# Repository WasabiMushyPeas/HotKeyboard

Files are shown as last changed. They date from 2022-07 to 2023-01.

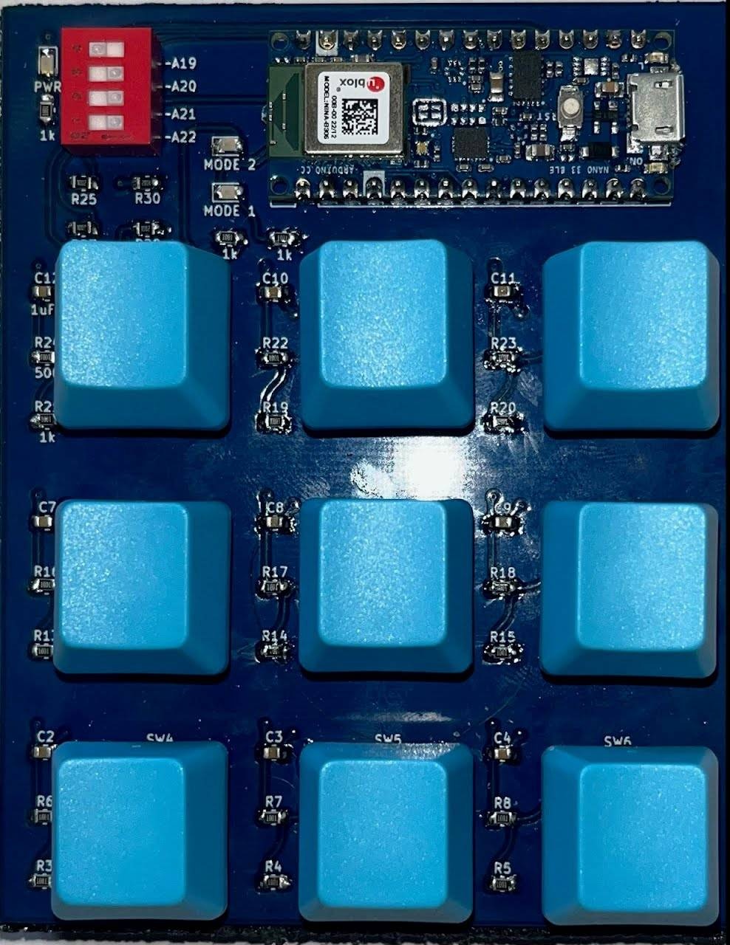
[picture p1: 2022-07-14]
pcbAndMaterials/signal-2022-07-12-220346.jpeg

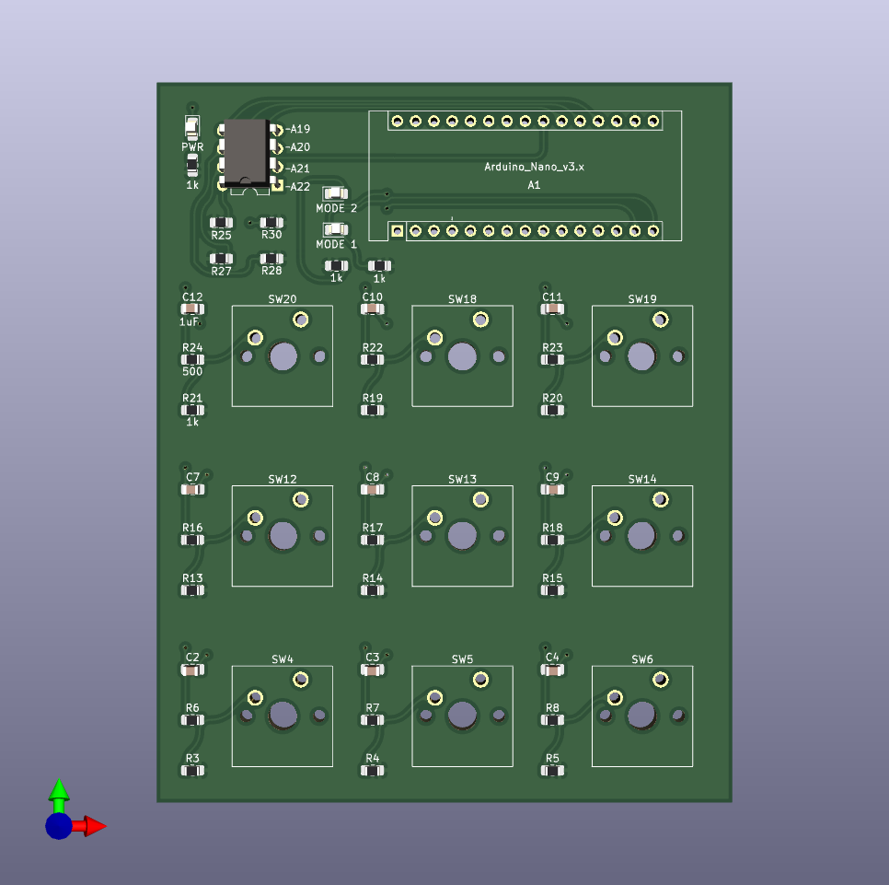
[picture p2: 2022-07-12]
pcbAndMaterials/PCB_Picture_Front.png

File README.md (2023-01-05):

# HotKey board
This is a simple Arduino project that allows Arduino boards that don't support Arduino's HID library to simulate key presses through a serial monitor accessed by python which than simulates the key presses. This repo also includes a PCB that connects 9 keyboard switches status LEDs and a DIP switch.
# Installation
- Download this git repo
- upload the [hotKeyBoard.ino](https://github.com/WasabiMushyPeas/HotKeyboard/blob/main/hotKeyBoard.ino) to your Arduino through the [Arduino IDE](https://www.arduino.cc/en/software)
- Pip install these Python libraries
`
pip install input
`
`
pip install serial
`
- make sure ser = serial. Serial('/dev/ttyACM0') in [keyBoardInterpriter.py](https://github.com/WasabiMushyPeas/HotKeyboard/blob/main/keyBoardInterpriter.py) on line 12 you replace '/dev/ttyACM0' with the port that your Arduino is connected to
- then run the python program
# Customization
if you want to customize your keyboard shortcuts edit the [keyBoardShortcuts.txt](https://github.com/WasabiMushyPeas/HotKeyboard/blob/main/keyBoardShortcuts.txt) and put your keyboard shortcuts in the text file like so:
```
cmd|g #cmd is short for the windows key or the command key on mac
Ctrl|h #this the command Ctrl+h | separates the key presses
Ctrl|Alt|Delete #This will be bound to the 3rd key and Ctrl|h the 2nd key and cmd|g the 1st key you can put up to 27. 
#The first key is the top left going from left to right then up to down.
```
> :warning: **Make sure you delete all the comments in [keyBoardShortcuts.txt](https://github.com/WasabiMushyPeas/HotKeyboard/blob/main/keyBoardShortcuts.txt) can not have comments**
# Other
if you need to excute commands on linux check out [the awesomewm branch](https://github.com/WasabiMushyPeas/HotKeyboard/tree/awesomewm)

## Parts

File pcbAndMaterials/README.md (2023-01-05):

# Custom PCB
if you would like to use my PCB design you need:
  - 0805 1k and 500ohm resistors and LEDs and 1uf capacitors
  - Arduino nano BLE
  - DIP switch with four switches
  - Cherry MX switches

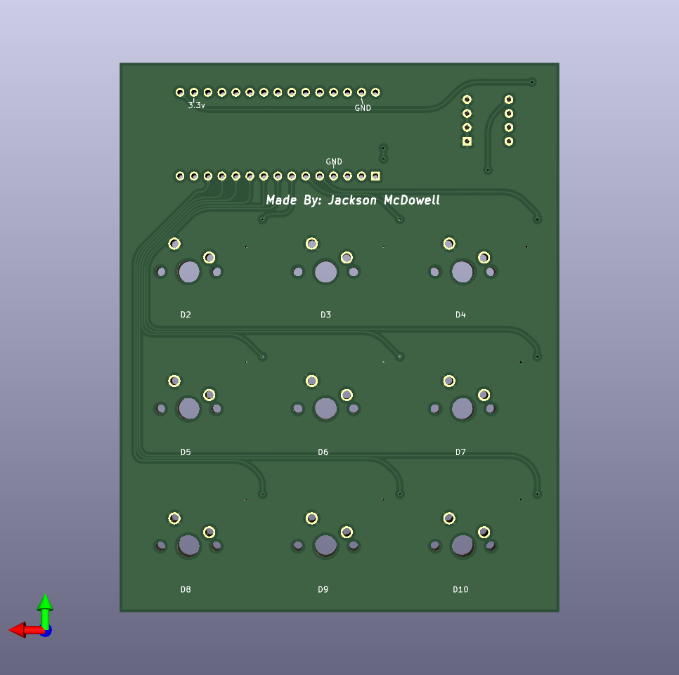
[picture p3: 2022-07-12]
pcbAndMaterials/PCB_Picture_Back.png

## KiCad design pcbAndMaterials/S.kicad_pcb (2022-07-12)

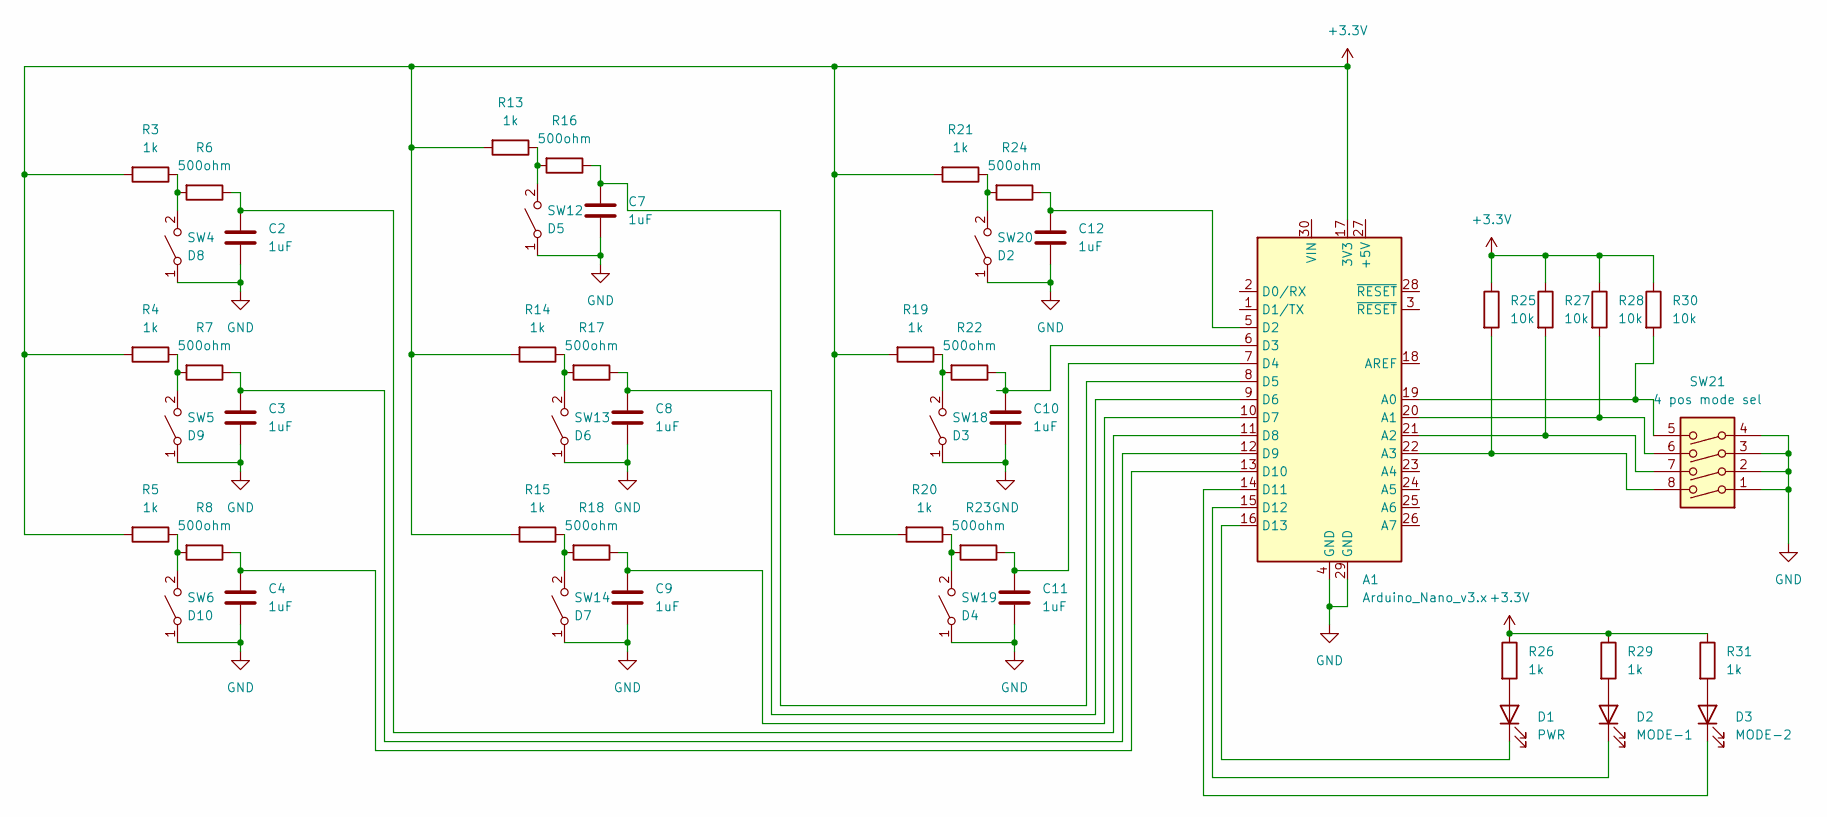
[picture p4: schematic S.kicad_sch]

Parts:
A1: Arduino_Nano_v3.x; Arduino_Nano
C2, C3, C4, C7, C8, C9, C10, C11, C12: 1uF; C_0805_2012Metric_Pad1.18x1.45mm_HandSolder
D1: PWR; LED_0805_2012Metric_Pad1.15x1.40mm_HandSolder
D2: MODE-1; LED_0805_2012Metric_Pad1.15x1.40mm_HandSolder
D3: MODE-2; LED_0805_2012Metric_Pad1.15x1.40mm_HandSolder
R3, R4, R5, R13, R14, R15, R19, R20, R21, R26, R29, R31: 1k; R_0805_2012Metric_Pad1.20x1.40mm_HandSolder
R6, R7, R8, R16, R17, R18, R22, R23, R24: 500ohm; R_0805_2012Metric_Pad1.20x1.40mm_HandSolder
R25, R27, R28, R30: 10k; R_0805_2012Metric_Pad1.20x1.40mm_HandSolder
SW4: D8; SW_Cherry_MX_1.00u_PCB
SW5: D9; SW_Cherry_MX_1.00u_PCB
SW6: D10; SW_Cherry_MX_1.00u_PCB
SW12: D5; SW_Cherry_MX_1.00u_PCB
SW13: D6; SW_Cherry_MX_1.00u_PCB
SW14: D7; SW_Cherry_MX_1.00u_PCB
SW18: D3; SW_Cherry_MX_1.00u_PCB
SW19: D4; SW_Cherry_MX_1.00u_PCB
SW20: D2; SW_Cherry_MX_1.00u_PCB
SW21: 4 pos mode sel; DIP-8_W7.62mm

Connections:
+3V3: A1.17 (3V3), R3.2, R4.2, R5.2, R13.2, R14.2, R15.2, R19.2, R20.2, R21.2, R25.1, R26.1, R27.1, R28.1, R29.1, R30.1, R31.1
GND: A1.4 (GND), A1.29 (GND), C2.2, C3.2, C4.2, C7.2, C8.2, C9.2, C10.2, C11.2, C12.2, SW4.1 (A), SW5.1 (A), SW6.1 (A), SW12.1 (A), SW13.1 (A), SW14.1 (A), SW18.1 (A), SW19.1 (A), SW20.1 (A), SW21.1, SW21.2, SW21.3, SW21.4
unnamed: A1.5 (D2), C12.1, R24.1
unnamed: A1.6 (D3), C10.1, R22.1
unnamed: A1.7 (D4), C11.1, R23.1
unnamed: A1.8 (D5), C7.1, R16.1
unnamed: A1.9 (D6), C8.1, R17.1
unnamed: A1.10 (D7), C9.1, R18.1
unnamed: A1.11 (D8), C2.1, R6.1
unnamed: A1.12 (D9), C3.1, R7.1
unnamed: A1.13 (D10), C4.1, R8.1
unnamed: A1.14 (D11), D3.1 (K)
unnamed: A1.15 (D12), D2.1 (K)
unnamed: A1.16 (D13), D1.1 (K)
unnamed: A1.19 (A0), R30.2, SW21.5
unnamed: A1.20 (A1), R28.2, SW21.6
unnamed: A1.21 (A2), R27.2, SW21.7
unnamed: A1.22 (A3), R25.2, SW21.8
unnamed: D1.2 (A), R26.2
unnamed: D2.2 (A), R29.2
unnamed: D3.2 (A), R31.2
unnamed: R3.1, R6.2, SW4.2 (B)
unnamed: R4.1, R7.2, SW5.2 (B)
unnamed: R5.1, R8.2, SW6.2 (B)
unnamed: R13.1, R16.2, SW12.2 (B)
unnamed: R14.1, R17.2, SW13.2 (B)
unnamed: R15.1, R18.2, SW14.2 (B)
unnamed: R19.1, R22.2, SW18.2 (B)
unnamed: R20.1, R23.2, SW19.2 (B)
unnamed: R21.1, R24.2, SW20.2 (B)

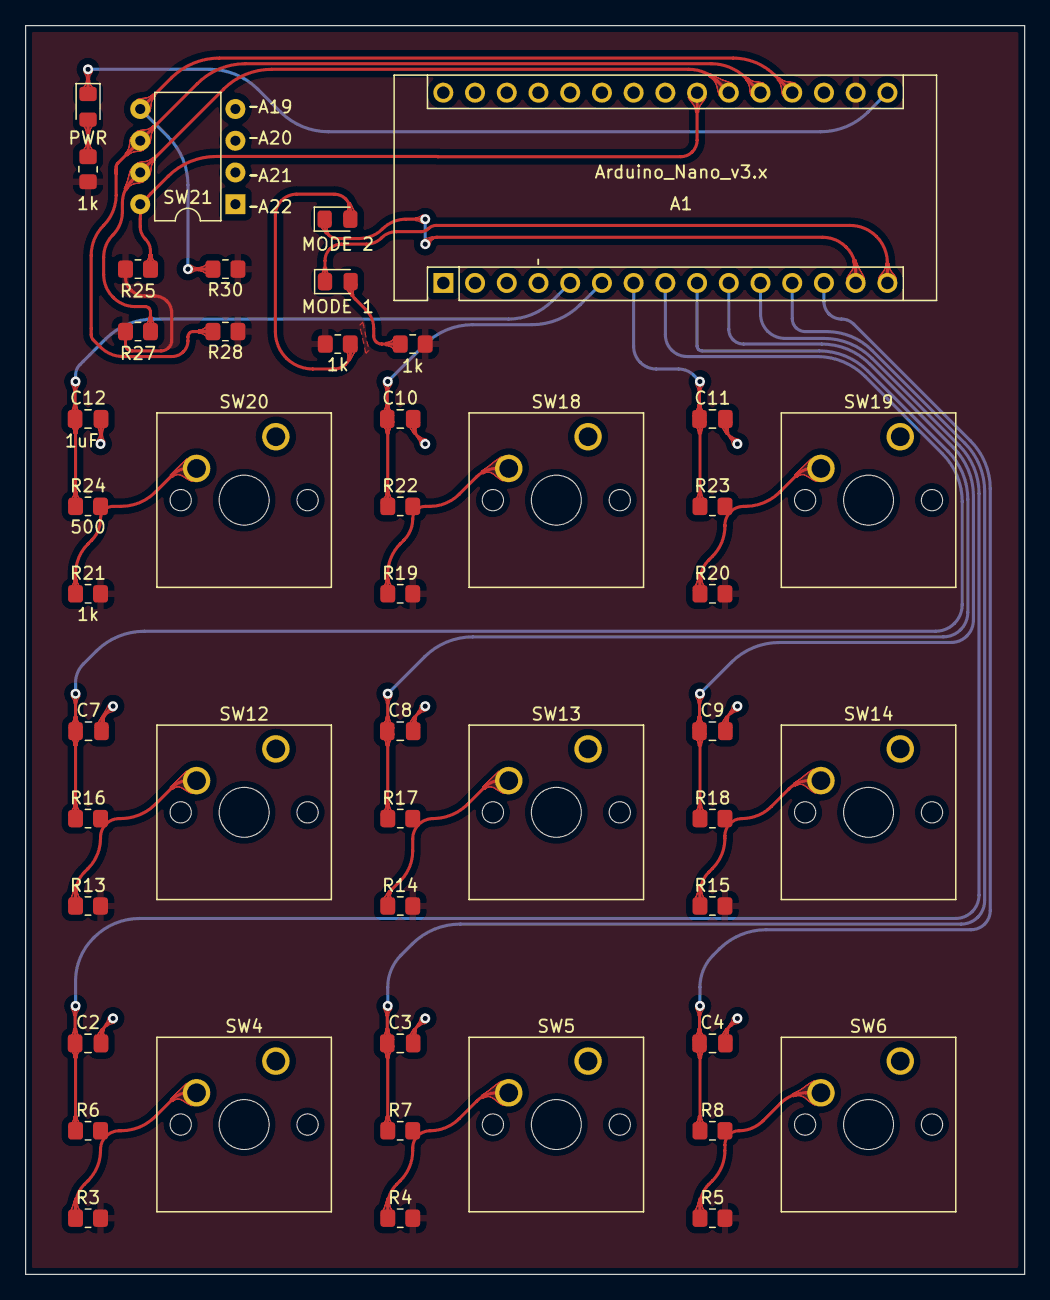
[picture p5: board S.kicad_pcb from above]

Board: 2 copper layers, 80.0 x 100.0 mm, 48 parts (0 on the bottom side), 30 nets.

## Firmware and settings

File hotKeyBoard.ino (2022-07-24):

const int BlueLEDbulitIn = 24;
const int RedLEDbulitIn = 22;
const int dipSwitch4 = A0;
const int dipSwitch3 = A1; 
const int dipSwitch2 = A2; 
const int dipSwitch1 = A3; 
const int mode2 = 11; 
const int mode1 = 12; 
const int sw20 = D2;
const int sw18 = D3;
const int sw19 = D4;
const int sw12 = D5;
const int sw13 = D6;
const int sw14 = D7;
const int sw4 = D8;
const int sw5 = D9;
const int sw6 = D10;

boolean canPressKey1 = true;
boolean canPressKey2 = true;
boolean canPressKey3 = true;
boolean canPressKey4 = true;
boolean canPressKey5 = true;
boolean canPressKey6 = true;
boolean canPressKey7 = true;
boolean canPressKey8 = true;
boolean canPressKey9 = true;

boolean dipSW4 = false;
boolean dipSW3 = false;
boolean dipSW2 = false;
boolean dipSW1 = false;

int addOn = 0;

const int sw1Num = 1;
const int sw2Num = 2;
const int sw3Num = 3;
const int sw4Num = 4;
const int sw5Num = 5;
const int sw6Num = 6;
const int sw7Num = 7;
const int sw8Num = 8;
const int sw9Num = 9;

void setup()
{
  pinMode(dipSwitch4, INPUT);

  digitalWrite(dipSwitch4, LOW);

  pinMode(mode2, OUTPUT);

  pinMode(sw20, INPUT);

  Serial.begin(9600);
  delay(3000);
  Serial.print("Starting up arduino nano 33 BLE with the hot key program\n");

}

void loop()
{
  if(digitalRead(dipSwitch4) == HIGH)  
  {
    digitalWrite(mode2, HIGH);
    dipSW4 = true;
    addOn = 0;
  }
  else{
    digitalWrite(mode2, LOW);
    dipSW4 = false;
  }
  
  if(digitalRead(dipSwitch3) == LOW)  
  {
    digitalWrite(mode1, LOW);
    dipSW3 = true;
    addOn = 9;
  }
  else {
    dipSW3 = false;
    digitalWrite(mode1, HIGH);
  }
  
  if(digitalRead(dipSwitch2) == LOW)  
  {
    dipSW2 = true;
    digitalWrite(mode1, LOW);
    digitalWrite(mode2, LOW);
    addOn = 18;
  }
  else{
    dipSW2 = false;
    digitalWrite(mode1, HIGH);
    digitalWrite(mode2, HIGH);
  }

  if(digitalRead(dipSwitch1) == LOW)  
  {
    dipSW1 = true;
    digitalWrite(RedLEDbulitIn, LOW);
  }
  else{
    dipSW1 = false;
    digitalWrite(RedLEDbulitIn, HIGH);
  }

  if(!dipSW1){
    
 
  if(digitalRead(sw20) == LOW){
    digitalWrite(BlueLEDbulitIn, LOW);
    if(canPressKey1){
      Serial.print(sw1Num + addOn);
      Serial.print("\n");
      canPressKey1 = false;
    }
  }else{
   digitalWrite(BlueLEDbulitIn, HIGH);
   if(!canPressKey1){
    canPressKey1 = true;
   }
  }
  if(digitalRead(sw18) == LOW){
    digitalWrite(BlueLEDbulitIn, LOW);
    if(canPressKey2){
      Serial.print(sw2Num + addOn);
      Serial.print("\n");
      canPressKey2 = false;
    }
  }else{
   digitalWrite(BlueLEDbulitIn, HIGH);
   if(!canPressKey2){
    canPressKey2 = true;
   }
  }
  if(digitalRead(sw19) == LOW){
    digitalWrite(BlueLEDbulitIn, LOW);
    if(canPressKey3){
      Serial.print(sw3Num + addOn);
      Serial.print("\n");
      canPressKey3 = false;
    }
  }else{
   digitalWrite(BlueLEDbulitIn, HIGH);
   if(!canPressKey3){
    canPressKey3 = true;
   }
  }
  if(digitalRead(sw12) == LOW){
    digitalWrite(BlueLEDbulitIn, LOW);
    if(canPressKey4){
      Serial.print(sw4Num + addOn);
      Serial.print("\n");
      canPressKey4 = false;
    }
  }else{
   digitalWrite(BlueLEDbulitIn, HIGH);
   if(!canPressKey4){
    canPressKey4 = true;
   }
  }
  if(digitalRead(sw13) == LOW){
    digitalWrite(BlueLEDbulitIn, LOW);
    if(canPressKey5){
      Serial.print(sw5Num + addOn);
      Serial.print("\n");
      canPressKey5 = false;
    }
  }else{
   digitalWrite(BlueLEDbulitIn, HIGH);
   if(!canPressKey5){
    canPressKey5 = true;
   }
  }
  if(digitalRead(sw14) == LOW){
    digitalWrite(BlueLEDbulitIn, LOW);
    if(canPressKey6){
      Serial.print(sw6Num + addOn);
      Serial.print("\n");
      canPressKey6 = false;
    }
  }else{
   digitalWrite(BlueLEDbulitIn, HIGH);
   if(!canPressKey6){
    canPressKey6 = true;
   }
  }
  if(digitalRead(sw4) == LOW){
    digitalWrite(BlueLEDbulitIn, LOW);
    if(canPressKey7){
      Serial.print(sw7Num + addOn);
      Serial.print("\n");
      canPressKey7 = false;
    }
  }else{
   digitalWrite(BlueLEDbulitIn, HIGH);
   if(!canPressKey7){
    canPressKey7 = true;
   }
  }
  if(digitalRead(sw5) == LOW){
    digitalWrite(BlueLEDbulitIn, LOW);
    if(canPressKey8){
      Serial.print(sw8Num + addOn);
      Serial.print("\n");
      canPressKey8 = false;
    }
  }else{
   digitalWrite(BlueLEDbulitIn, HIGH);
   if(!canPressKey8){
    canPressKey8 = true;
   }
  }
  if(digitalRead(sw6) == LOW){
    digitalWrite(BlueLEDbulitIn, LOW);
    if(canPressKey9){
      Serial.print(sw9Num + addOn);
      Serial.print("\n");
      canPressKey9 = false;
    }
  }else{
   digitalWrite(BlueLEDbulitIn, HIGH);
   if(!canPressKey9){
    canPressKey9 = true;
   }
  }
  
  }
  
}

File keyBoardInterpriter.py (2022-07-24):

import serial
from pynput.keyboard import Key, Controller, KeyCode
import time
import os

Keyboard = Controller()

keyBoardSCfile = open("keyBoardShortcuts.txt", "r")
keyBoardShortcuts = keyBoardSCfile.readlines()
keyBoardSCfile.close()

ser = serial.Serial('/dev/ttyACM0')
while True:
    keyNum = ser.readline()
    keyNum = str(keyNum)
    keyNum = keyNum.replace("b", "").replace("\'", "").replace("\\n", "")

    print(keyNum)
    if(True):
        indivualKeys = keyBoardShortcuts[(int(keyNum)) - 1].split("|")

        x = 0
        for key in indivualKeys:
            indivualKeys[x] = key.replace('\n', '')
            x += 1
        
        for key in indivualKeys:
            if(key == "cmd"):
                print("press: " + key)
                Keyboard.press(Key.cmd)
            elif(key == "Ctrl"):
                Keyboard.press(Key.ctrl)
            elif(key == "Shift"):
                Keyboard.press(Key.shift)
            elif(key == "alt"):
                Keyboard.press(Key.alt)
            elif(key == "Enter"):
                Keyboard.press(Key.enter)
            elif(key == "Tab"):
                Keyboard.press(Key.tab)
            elif(key == "Esc"):
                Keyboard.press(Key.esc)
            elif(key == "Delete"):
                Keyboard.press(Key.delete)
            elif(key == "Backspace"):
                Keyboard.press(Key.backspace)
            else:
                print("press: " + key)
                Keyboard.press(KeyCode.from_char(key))

        time.sleep(0.1)
        for key in indivualKeys:
            if(key == "cmd"):
                print("release: " + key)
                Keyboard.release(Key.cmd)
            elif(key == "Ctrl"):
                Keyboard.release(Key.ctrl)
            elif(key == "Shift"):
                Keyboard.release(Key.shift)
            elif(key == "alt"):
                Keyboard.release(Key.alt)
            elif(key == "Enter"):
                Keyboard.release(Key.enter)
            elif(key == "Tab"):
                Keyboard.release(Key.tab)
            elif(key == "Esc"):
                Keyboard.release(Key.esc)
            elif(key == "Delete"):
                Keyboard.release(Key.delete)
            elif(key == "Backspace"):
                Keyboard.release(Key.backspace)
            else:
                print("release: " + key)
                Keyboard.release(KeyCode.from_char(key))

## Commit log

2022-07-10 added arduino file
2022-07-12 allows dip switch 1 to turn off key board output
2022-07-12 Added pcbAndMaterials folder with a readme file
2022-07-12 added the pcb files
    [S.kicad_pcb, S.kicad_sch]
2022-07-12 Added renders of the pcb
2022-07-14 real pcb pic
2022-07-24 bug fix with dip 1
    Fixed a bug that happened when the Arduino read the inverse of dip switch 1 which controls if the key board outputs anything or not.
    [keyBoardInterpriter.py, onKeyboardPlugIn.py]
2022-07-24 Fixed bug with dip switch 1
    [hotKeyBoard.ino]
